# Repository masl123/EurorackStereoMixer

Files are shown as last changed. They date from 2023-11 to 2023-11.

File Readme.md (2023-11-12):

## Eurorack Stereo Mixer

This Eurorack module allows to mix stereo signals from up to 4 channels into one while also allowing to 
change the volume for each of the channels. The master volume can also be changed.
By plugging a mono signal into the left input of a channel, the signal is mirrored to the right 
channel of the mixer. This allows for mixing mono and stereo signals.

The module consists of 2 PCBs and a Frontpanel.

Based on a design from [circuitbasics](https://www.circuitbasics.com/what-are-audio-mixers/).

**Note**: The current release 1.0 is untested. I did test version 0.1 however
and it does work fine. Only some smaller adjustments were made in comparison to the version I built.

### Releases
Check the release folder for the different releases of this module and the corresponding BOMs.
Included gerber files should work for JLC-PCB. 

### Images

| | | 
|---|---|
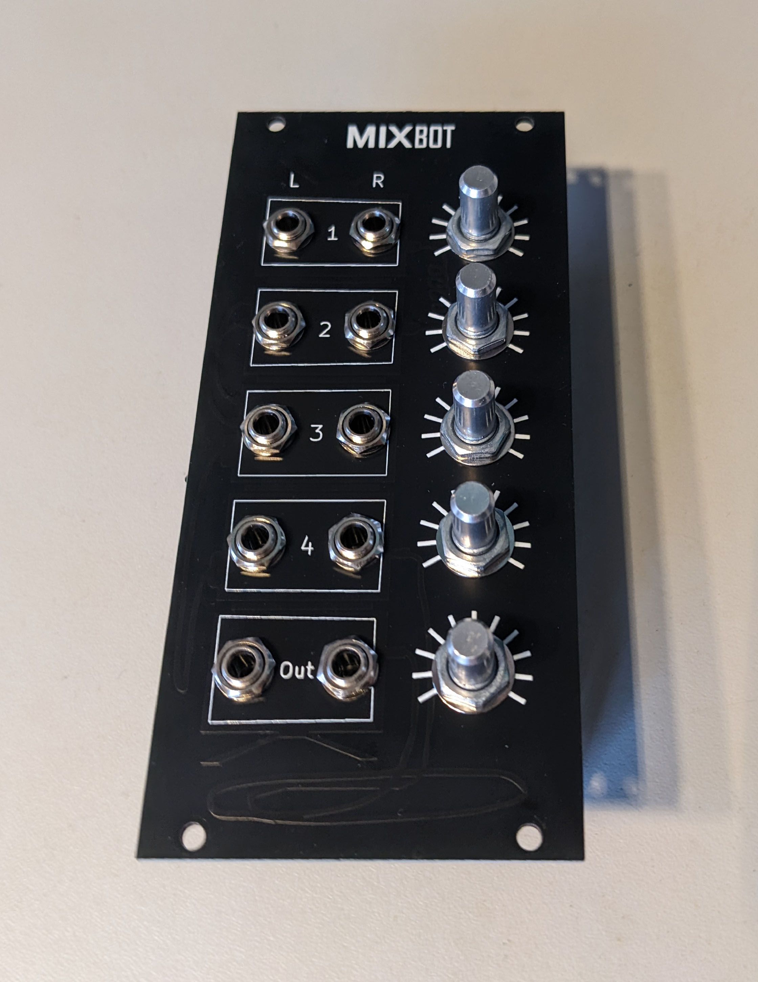
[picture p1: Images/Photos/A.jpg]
Front_1
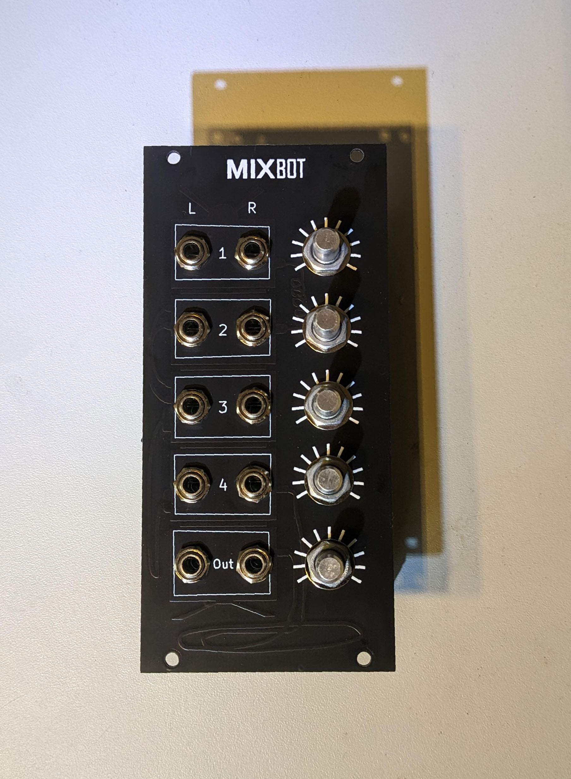
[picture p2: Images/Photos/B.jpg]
Front_2
|   |   |
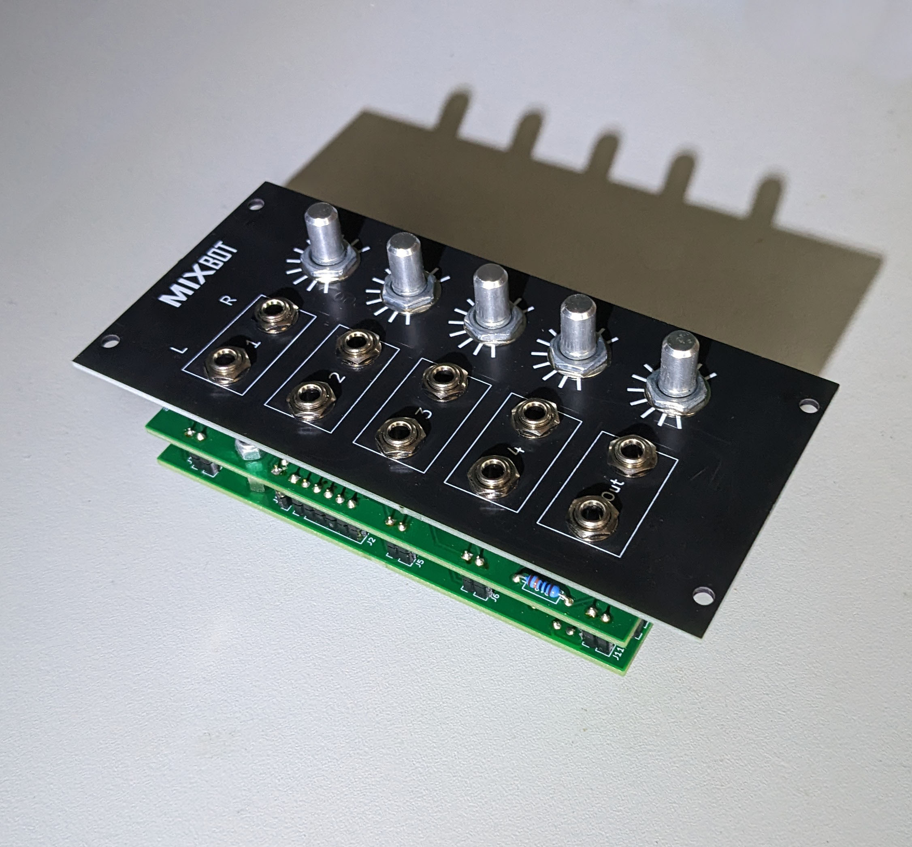
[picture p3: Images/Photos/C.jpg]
Side_1
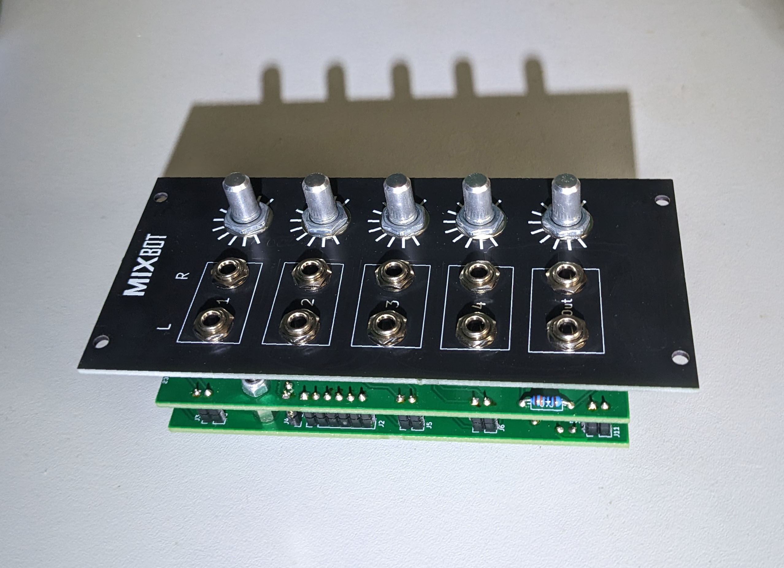
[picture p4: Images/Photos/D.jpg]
Side_2
|  |    |
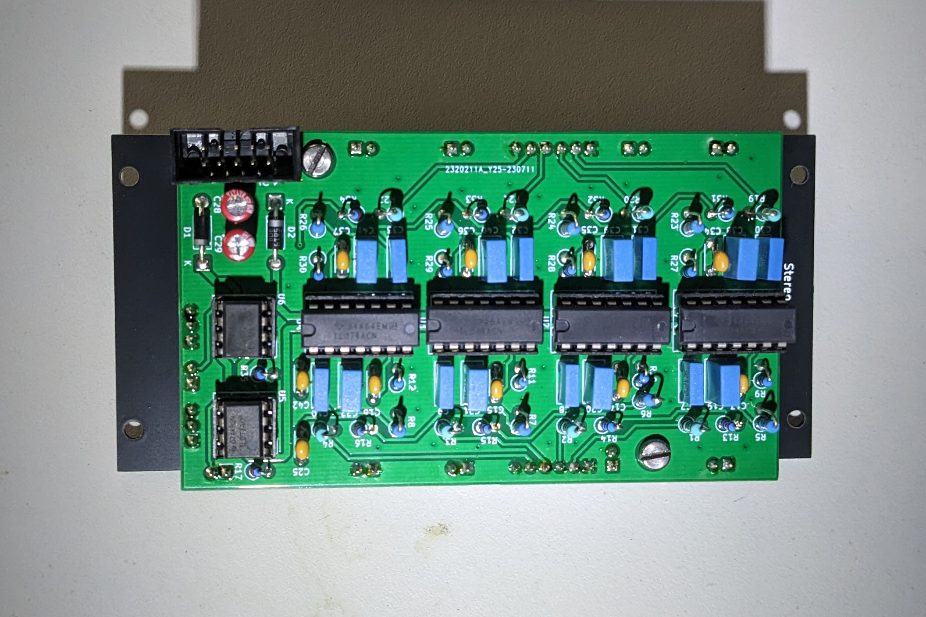
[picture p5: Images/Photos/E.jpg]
Back_1
|  | |

### Changelog
Version 0.1:
 - initial design done

Version 1.0:
 - initial public release
 - placement of one potentiometer was slightly off.
 - adjusted text on PCBs slightly to include the repository name and license information

### License
Licensed under the TAPR Open Hardware License (www.tapr.org/OHL)

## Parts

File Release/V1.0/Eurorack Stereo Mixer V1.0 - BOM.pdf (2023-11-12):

Qty | Reference(s) | Value | Part | Footprint
| 10 A1, A2, A3, A4, A5, A6, A7, A8, A9, A10 | | PJ398SM
| 14 C1, C2, C3, C4, C5, C6, C11, C12, C17, C18, C23, C24, C26, C27 | 100n | CC0805KPX7R9104 | 0805 MLCC
| 8 C7, C8, C9, C10, C30, C31, C32, C33 | 220n | B32529C0224J000 | 5mm Film
| 8 C13, C14, C15, C16, C34, C35, C36, C37 | 47p | CT40805N470J500F3R | 5mm MLCC
| 8 C19, C20, C21, C22, C38, C39, C40, C41 | 470n | B32529C0474J289 | 5mm Film
| 2 C25, C42 | 220p | CT40805N221J500F3R | 5mm MLCC
| 2 C28, C29 | 10u | EEUEB1A101S | 5mm Rad. | 2mm Pin Pitch | Electrolytic
| 2 D1, D2 | | 1N5819 | DO-41
| 2 J1, J16 | | 01x06 Socket | 2.54mm Pin Pitch
| 2 J2, J17 | | 01x06 Header | 2.54mm Pin Pitch
| 10 J7, J8, J9, J10, J12, J22, J23, J24, J25, J27 | | 01x02 Socket | 2.54mm Pin Pitch
| 10 J3, J4, J5, J6, J11, J18, J19, J20, J21, J26 | | 01x02 Header | 2.54mm Pin Pitch
| 2 J15, J29 | | 01x03 Socket | 2.54mm Pin Pitch
| 2 J14, J28 | | 01x03 Header | 2.54mm Pin Pitch
| 1 J13 | | 02x05 (Shrouded) Header | 2.54mm Pin Pitch
| 8 R1, R2, R3, R4, R19, R20, R21, R22 | 10k | | 0.4 or 0.6 Watt / 1%
| 8 R5, R6, R7, R8, R23, R24, R25, R26 | 43k | | 0.4 or 0.6 Watt / 1%
| 8 R9, R10, R11, R12, R27, R28, R29, R30 | 1M | | 0.4 or 0.6 Watt / 1%
| 10 R13, R14, R15, R16, R17, R31, R32, R33, R34, R35 | 20k | | 0.4 or 0.6 Watt / 1%
| 2 R18, R36 | 100k | | 0.4 or 0.6 Watt / 1%
| 5 RV1, RV2, RV3, RV4, RV5 | A100k | https://www.thonk.co.uk/shop/alpha-9mm-pots/ | DUAL GANG - Round Shaft 6.35mm
| 4 U1, U2, U3, U4 | | TL074 | DIP14
| 2 U5, U6 | | TL072 | DIP8

# Eurorack Stereo Mixer - BOM

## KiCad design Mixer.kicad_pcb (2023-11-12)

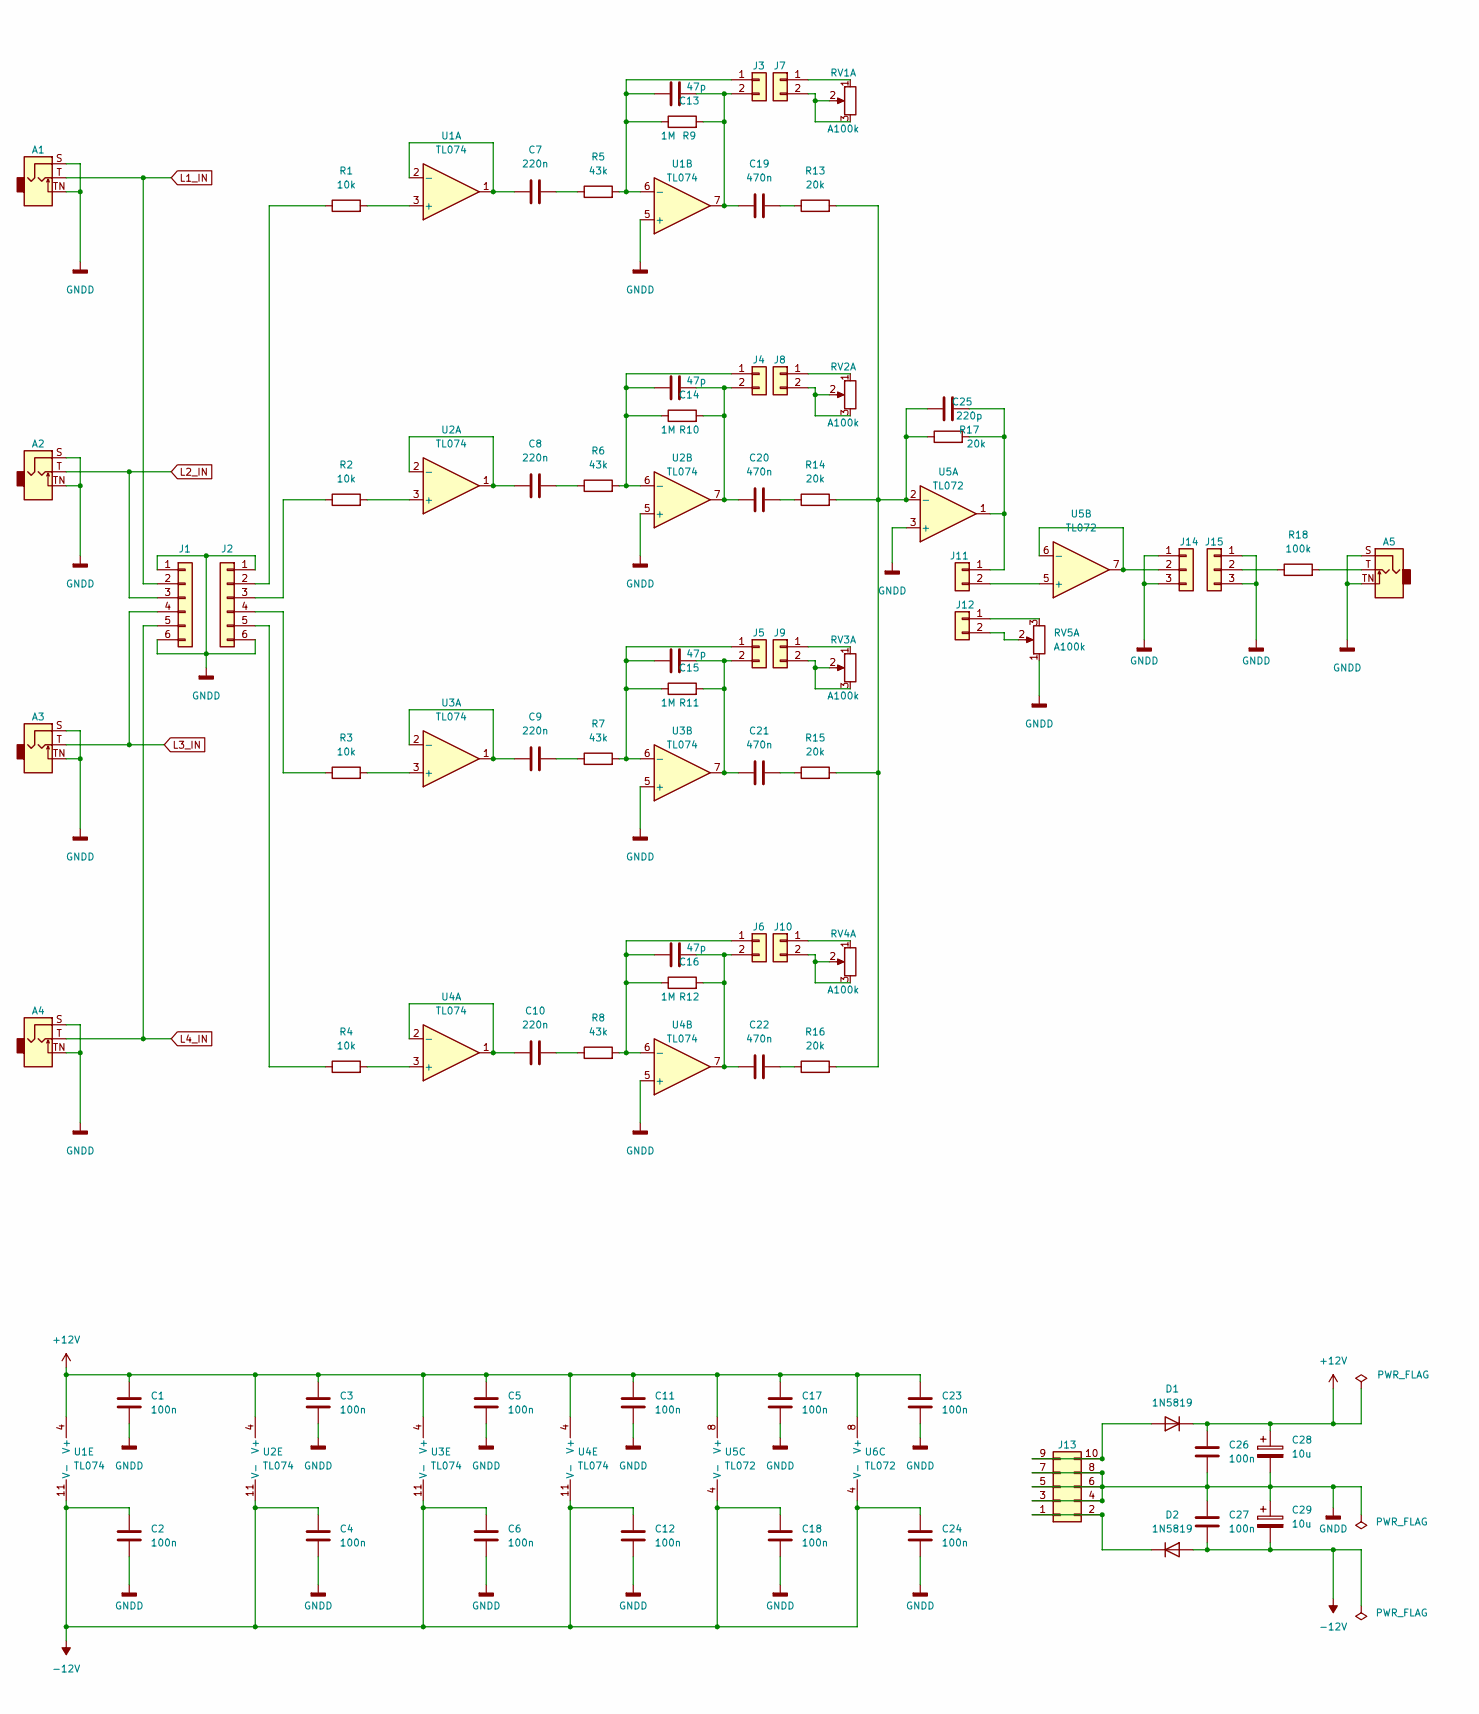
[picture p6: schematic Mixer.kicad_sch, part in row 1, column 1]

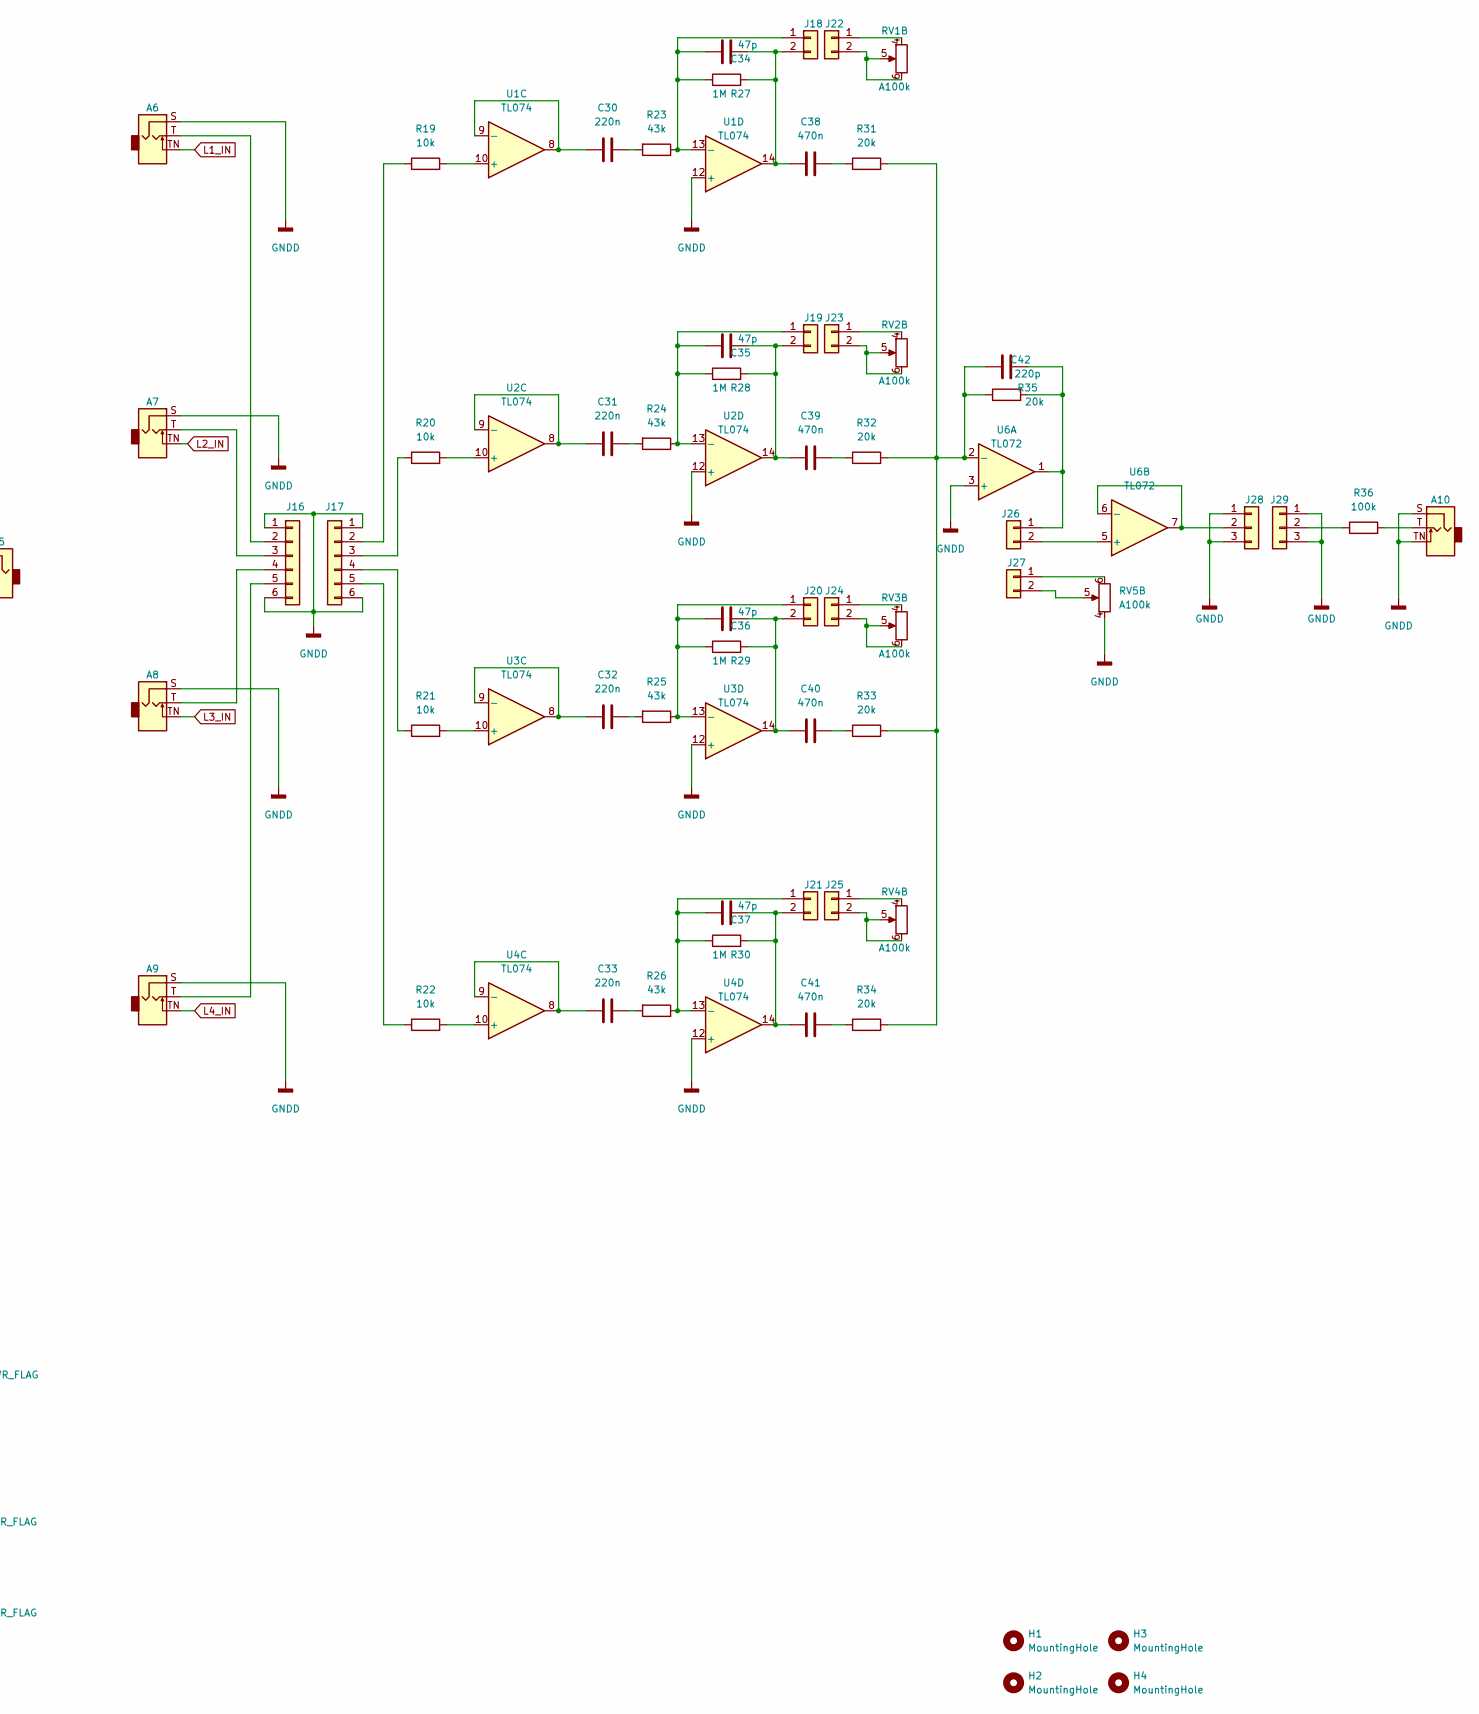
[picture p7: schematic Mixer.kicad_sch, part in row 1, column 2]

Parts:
A1, A2, A3, A4, A5, A6, A7, A8, A9, A10: Jack_3.5mm_QingPu_WQP-PJ398SM_Vertical
C1, C2, C3, C4, C5, C6, C11, C12, C17, C18, C23, C24, C26, C27: 100n; C_0805_2012Metric_Pad1.18x1.45mm_HandSolder; Part CC0805KPX7R9104
C7, C8, C9, C10, C30, C31, C32, C33: 220n; C_Rect_L7.2mm_W2.5mm_P5.00mm_FKS2_FKP2_MKS2_MKP2; Part B32529C0224J000
C13, C14, C15, C16, C34, C35, C36, C37: 47p; C_Disc_D4.3mm_W1.9mm_P5.00mm; Part CT40805N470J500F3R
C19, C20, C21, C22, C38, C39, C40, C41: 470n; C_Rect_L7.2mm_W3.5mm_P5.00mm_FKS2_FKP2_MKS2_MKP2; Part B32529C0474J289
C25, C42: 220p; C_Disc_D4.3mm_W1.9mm_P5.00mm; Part CT40805N221J500F3R
C28, C29: 10u; CP_Radial_D5.0mm_P2.00mm; Part EEUEB1A101S
D1, D2: 1N5819; D_DO-41_SOD81_P10.16mm_Horizontal
H1, H2, H3, H4: MountingHole; MountingHole_3.2mm_M3
J1, J16: Conn_01x06; PinSocket_1x06_P2.54mm_Vertical
J2, J17: Conn_01x06; PinHeader_1x06_P2.54mm_Vertical
J3, J4, J5, J6, J11, J18, J19, J20, J21, J26: Conn_01x02; PinHeader_1x02_P2.54mm_Vertical
J7, J8, J9, J10, J12, J22, J23, J24, J25, J27: Conn_01x02; PinSocket_1x02_P2.54mm_Vertical
J13: PinHeader_2x05_P2.54mm_Vertical
J14, J28: Conn_01x03; PinHeader_1x03_P2.54mm_Vertical
J15, J29: Conn_01x03; PinSocket_1x03_P2.54mm_Vertical
R1, R2, R3, R4, R19, R20, R21, R22: 10k; R_Axial_DIN0207_L6.3mm_D2.5mm_P2.54mm_Vertical
R5, R6, R7, R8, R23, R24, R25, R26: 43k; R_Axial_DIN0207_L6.3mm_D2.5mm_P2.54mm_Vertical
R9, R10, R11, R12, R27, R28, R29, R30: 1M; R_Axial_DIN0207_L6.3mm_D2.5mm_P2.54mm_Vertical
R13, R14, R15, R16, R17, R31, R32, R33, R34, R35: 20k; R_Axial_DIN0207_L6.3mm_D2.5mm_P2.54mm_Vertical
R18, R36: 100k; R_Axial_DIN0207_L6.3mm_D2.5mm_P10.16mm_Horizontal
RV1, RV2, RV3, RV4, RV5: A100k; Potentiometer_Alpha_RD902F-40-00D_Dual_Vertical
U1, U2, U3, U4: TL074; DIP-14_W7.62mm_Socket_LongPads
U5, U6: TL072; DIP-8_W7.62mm_Socket_LongPads

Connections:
+12V: C1.1, C3.1, C5.1, C11.1, C17.1, C23.1, C26.1, C28.1, D1.1 (K), U1.4 (V+), U2.4 (V+), U3.4 (V+), U4.4 (V+), U5.8 (V+), U6.8 (V+)
-12V: C2.1, C4.2, C6.2, C12.2, C18.2, C24.2, C27.2, C29.2, D2.2 (A), U1.11 (V-), U2.11 (V-), U3.11 (V-), U4.11 (V-), U5.4 (V-), U6.4 (V-)
GNDD: A1.S, A1.TN, A2.S, A2.TN, A3.S, A3.TN, A4.S, A4.TN, A5.S, A5.TN, A6.S, A7.S, A8.S, A9.S, A10.S, A10.TN, C1.2, C2.2, C3.2, C4.1, C5.2, C6.1, C11.2, C12.1, C17.2, C18.1, C23.2, C24.1, C26.2, C27.1, C28.2, C29.1, J1.1, J1.6, J2.1, J2.6, J13.3, J13.4, J13.5, J13.6, J13.7, J13.8, J14.1, J14.3, J15.1, J15.3, J16.1, J16.6, J17.1, J17.6, J28.1, J28.3, J29.1, J29.3, RV5.1, RV5.4, U1.5 (+), U1.12 (+), U2.5 (+), U2.12 (+), U3.5 (+), U3.12 (+), U4.5 (+), U4.12 (+), U5.3 (+), U6.3 (+)
L1_IN: A1.T, A6.TN, J1.2
L2_IN: A2.T, A7.TN, J1.3
L3_IN: A3.T, A8.TN, J1.4
L4_IN: A4.T, A9.TN, J1.5
unnamed: A5.T, R18.2
unnamed: A6.T, J16.2
unnamed: A7.T, J16.3
unnamed: A8.T, J16.4
unnamed: A9.T, J16.5
unnamed: A10.T, R36.2
unnamed: C7.1, R5.1
unnamed: C7.2, U1.1, U1.2 (-)
unnamed: C8.1, R6.1
unnamed: C8.2, U2.1, U2.2 (-)
unnamed: C9.1, R7.1
unnamed: C9.2, U3.1, U3.2 (-)
unnamed: C10.1, R8.1
unnamed: C10.2, U4.1, U4.2 (-)
unnamed: C13.1, J3.1, R5.2, R9.1, U1.6 (-)
unnamed: C13.2, C19.1, J3.2, R9.2, U1.7
unnamed: C14.1, J4.1, R6.2, R10.1, U2.6 (-)
unnamed: C14.2, C20.1, J4.2, R10.2, U2.7
unnamed: C15.1, J5.1, R7.2, R11.1, U3.6 (-)
unnamed: C15.2, C21.1, J5.2, R11.2, U3.7
unnamed: C16.1, J6.1, R8.2, R12.1, U4.6 (-)
unnamed: C16.2, C22.1, J6.2, R12.2, U4.7
unnamed: C19.2, R13.1
unnamed: C20.2, R14.1
unnamed: C21.2, R15.1
unnamed: C22.2, R16.1
unnamed: C25.1, R13.2, R14.2, R15.2, R16.2, R17.1, U5.2 (-)
unnamed: C25.2, J11.1, R17.2, U5.1
unnamed: C30.1, U1.8, U1.9 (-)
unnamed: C30.2, R23.2
unnamed: C31.1, U2.8, U2.9 (-)
unnamed: C31.2, R24.2
unnamed: C32.1, U3.8, U3.9 (-)
unnamed: C32.2, R25.2
unnamed: C33.1, U4.8, U4.9 (-)
unnamed: C33.2, R26.2
unnamed: C34.1, J18.1, R23.1, R27.1, U1.13 (-)
unnamed: C34.2, C38.1, J18.2, R27.2, U1.14
unnamed: C35.1, J19.1, R24.1, R28.1, U2.13 (-)
unnamed: C35.2, C39.1, J19.2, R28.2, U2.14
unnamed: C36.1, J20.1, R25.1, R29.1, U3.13 (-)
unnamed: C36.2, C40.1, J20.2, R29.2, U3.14
unnamed: C37.1, J21.1, R26.1, R30.1, U4.13 (-)
unnamed: C37.2, C41.1, J21.2, R30.2, U4.14
unnamed: C38.2, R31.1
unnamed: C39.2, R32.1
unnamed: C40.2, R33.1
unnamed: C41.2, R34.1
unnamed: C42.1, R31.2, R32.2, R33.2, R34.2, R35.1, U6.2 (-)
unnamed: C42.2, J26.1, R35.2, U6.1
unnamed: D1.2 (A), J13.9, J13.10
unnamed: D2.1 (K), J13.1, J13.2
unnamed: J2.2, R1.1
unnamed: J2.3, R2.1
unnamed: J2.4, R3.1
unnamed: J2.5, R4.1
unnamed: J7.1, RV1.1
unnamed: J7.2, RV1.2, RV1.3
unnamed: J8.1, RV2.1
unnamed: J8.2, RV2.2, RV2.3
unnamed: J9.1, RV3.1
unnamed: J9.2, RV3.2, RV3.3
unnamed: J10.1, RV4.1
unnamed: J10.2, RV4.2, RV4.3
unnamed: J11.2, U5.5 (+)
unnamed: J12.1, RV5.3
unnamed: J12.2, RV5.2
unnamed: J14.2, U5.6 (-), U5.7
unnamed: J15.2, R18.1
unnamed: J17.2, R19.1
unnamed: J17.3, R20.1
unnamed: J17.4, R21.1
unnamed: J17.5, R22.1
unnamed: J22.1, RV1.4
unnamed: J22.2, RV1.5, RV1.6
unnamed: J23.1, RV2.4
unnamed: J23.2, RV2.5, RV2.6
unnamed: J24.1, RV3.4
unnamed: J24.2, RV3.5, RV3.6
unnamed: J25.1, RV4.4
unnamed: J25.2, RV4.5, RV4.6
unnamed: J26.2, U6.5 (+)
unnamed: J27.1, RV5.6
unnamed: J27.2, RV5.5
unnamed: J28.2, U6.6 (-), U6.7
unnamed: J29.2, R36.1
unnamed: R1.2, U1.3 (+)
unnamed: R2.2, U2.3 (+)
unnamed: R3.2, U3.3 (+)
unnamed: R4.2, U4.3 (+)
unnamed: R19.2, U1.10 (+)
unnamed: R20.2, U2.10 (+)
unnamed: R21.2, U3.10 (+)
unnamed: R22.2, U4.10 (+)

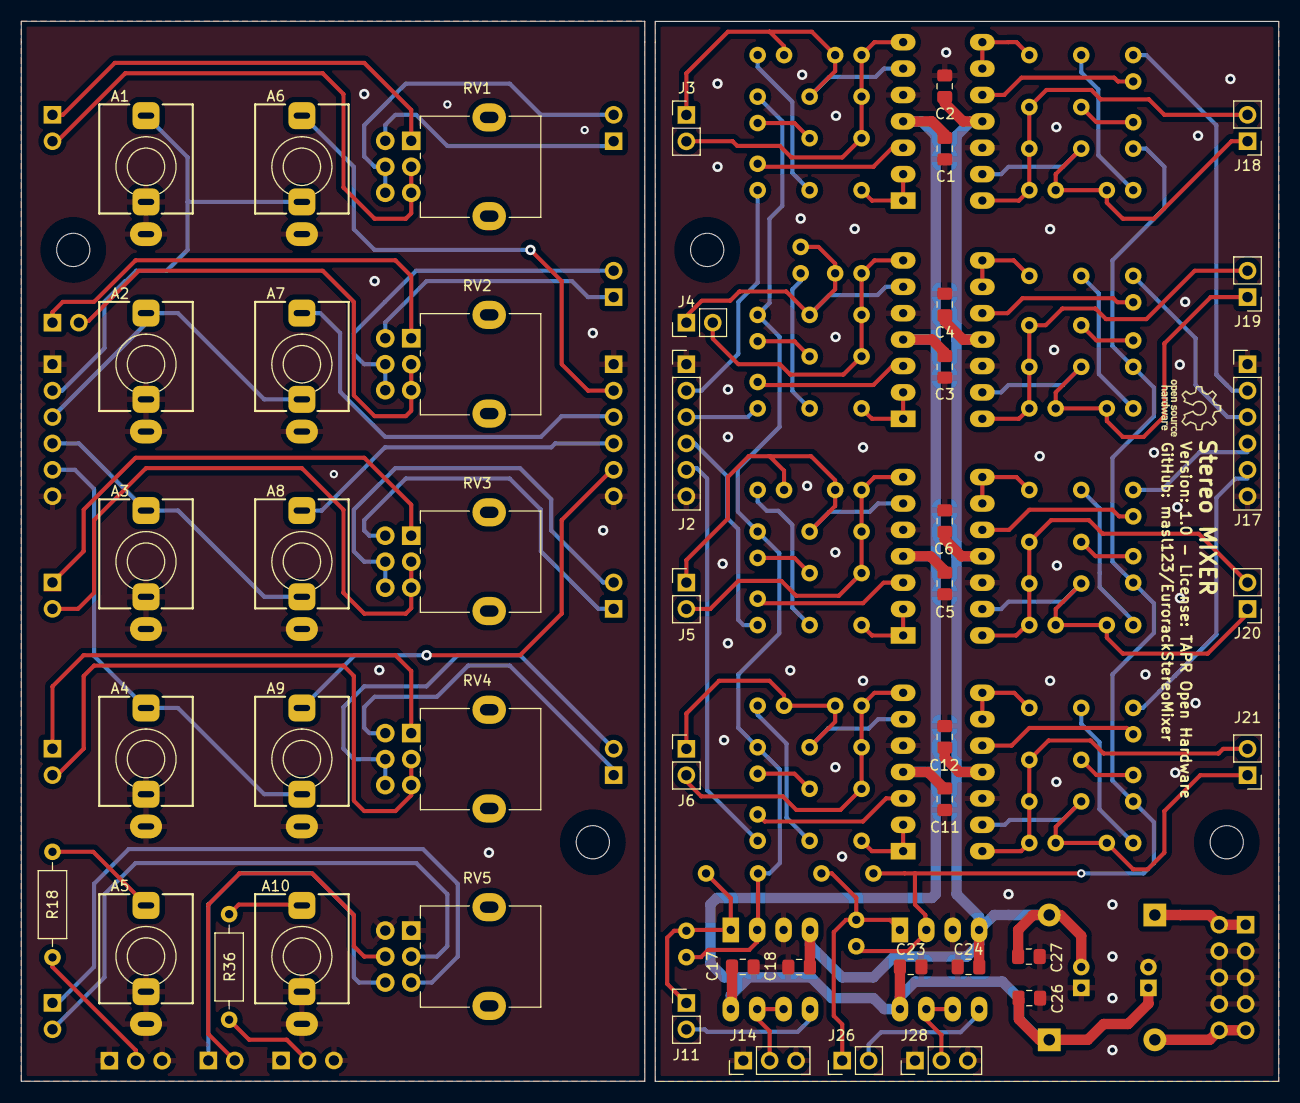
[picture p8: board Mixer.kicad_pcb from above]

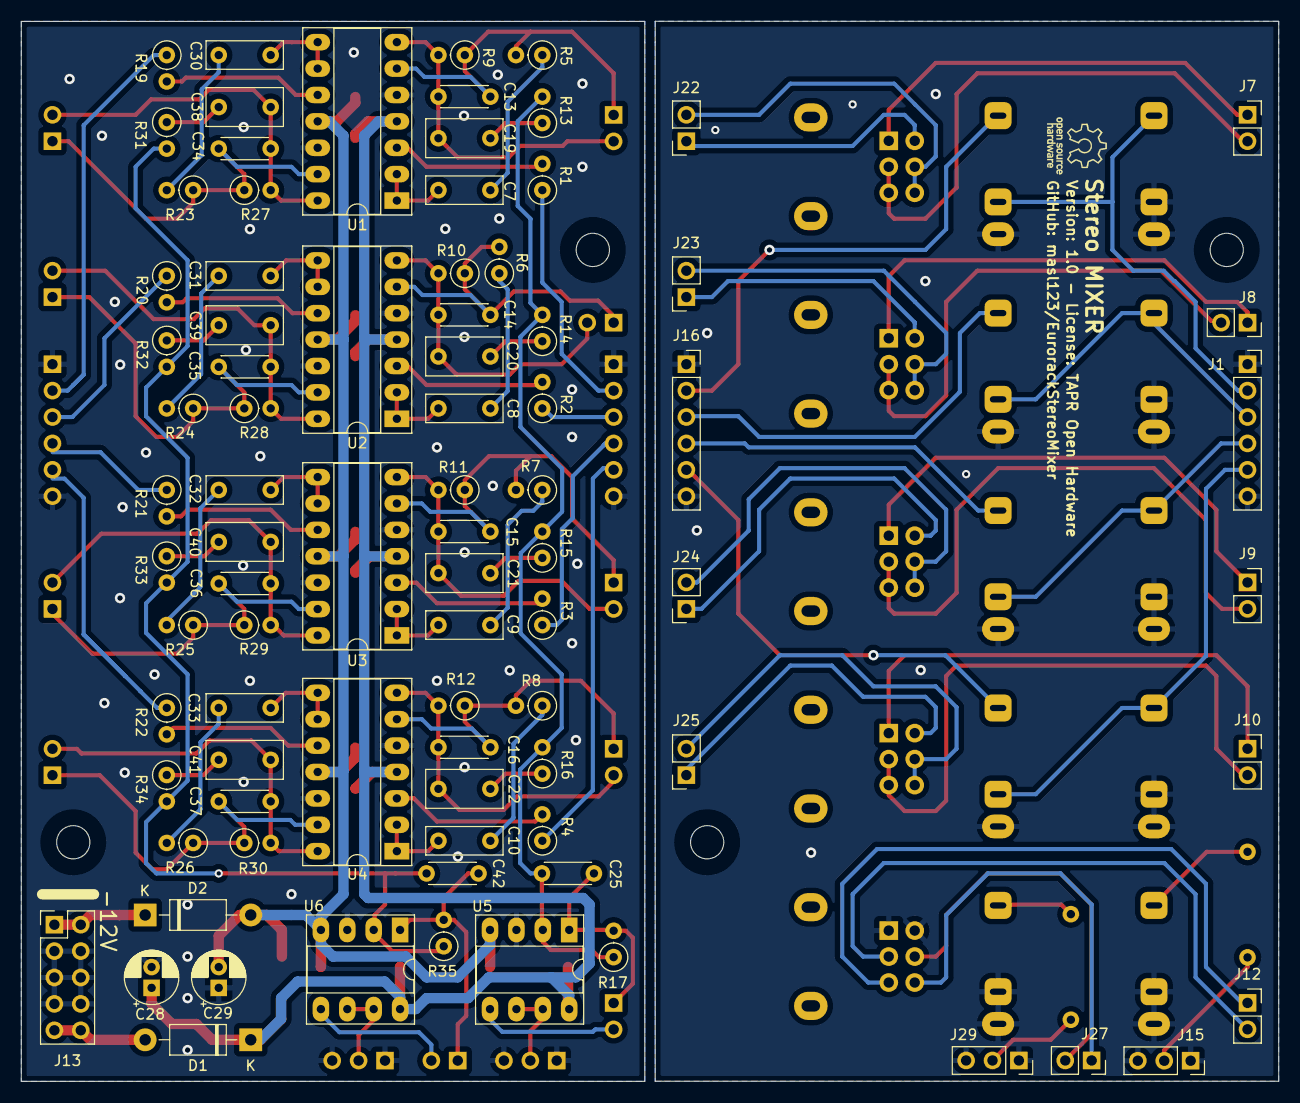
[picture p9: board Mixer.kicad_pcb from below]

Board: 2 copper layers, 121.0 x 102.0 mm, 134 parts (85 on the bottom side), 101 nets.

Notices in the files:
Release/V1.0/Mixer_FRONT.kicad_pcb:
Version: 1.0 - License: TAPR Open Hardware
